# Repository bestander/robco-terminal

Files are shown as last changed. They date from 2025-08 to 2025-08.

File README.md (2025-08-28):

# Fallout RobCo Terminal Project

A fully functional Fallout-style terminal interface for ESP32-S3 with 7" display, featuring authentic RobCo Industries theming, MQTT integration with Home Assistant, and text editor capabilities.

Demo

## Hardware Requirements

- ESP32-S3 HMI 8M PSRAM 16M Flash with 7" 800x480 RGB LCD display
- USB keyboard (USB host implemented by Raspberry Pi Pico connected via UART; firmware: https://github.com/bestander/pi-pico-usb-uart-host)
- WiFi network with Home Assistant + MQTT broker

## Hardware Reference

- [7" 800*480 with ESP32-S3](https://www.aliexpress.us/item/3256807606021455.html)
- USB keyboard [40% mechanical fits the STL](https://www.aliexpress.us/item/3256808357667662.html)
- [Raspberry Pi Pico](https://www.amazon.com/Raspberry-Pi-Pico/dp/B09KVB8LVR) to be used as extension board and a USB HID master
- [Micro USB OTG cable](https://www.amazon.com/dp/B0BX9FSCFH) to connect the keyboard to Pico
- USB-A - USB-C cable to connect the keyboard to the OTG cable
- [Right angle USBC cable](https://www.amazon.com/dp/B0DQS6FTX3) to power and flash the ESP32-S3 board when mounted
- [Frensel lense](https://www.amazon.com/dp/B015NR7XGS) for CRT display affect
- 2 LED and 100-150 Ohm resistors and wire soldered to pins 17 and 21 on Pi Pico for additional signaling

## 3D Print case

See [assets/stl](./assets/stl) for all the 3D printed parts. You'll need a few screws to connect the pieces and a drop of glue to secure wall rest to the keyboard part to prevent it from shaking. 
Feel free to fork the design in [onshape](https://cad.onshape.com/documents/a596f804bfbdc16828dea787/w/d24c8487b87e16e2d8c3f80b/e/312ff6ea062bc67b4dcde5d5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).

## Features

✅ **Authentic Fallout Terminal Experience**
- RobCo Industries boot sequence
- Green terminal text on black background
- Blinking cursor animation
- Terminal-style UI navigation

✅ **Home Assistant Integration**
- MQTT command/control interface
- Real-time status updates
- Conditional menu items based on device states

✅ **Navigation System**
- Multi-level menu navigation
- USB keyboard support (Arrow keys, Enter, Escape)
- Context-sensitive menu items

✅ **Text Editor** (not implemented)
- Built-in log editor
- File-based storage
- Terminal-style editing interface

## Configuration

```yaml
wifi_password: "your_wifi_password"
api_encryption_key: "32-character-key-generated-by-esphome"
ota_password: "your_ota_password"
mqtt_broker: "192.168.1.100"  # Your Home Assistant IP
mqtt_username: "your_mqtt_username"
mqtt_password: "your_mqtt_password"
```

## Home Assistant: MQTT Configuration

1. **Install the Mosquitto broker add-on** (recommended):
   - Go to **Settings > Add-ons > Add-on Store**.
   - Search for "Mosquitto broker" and install it.
   - Start the add-on.

2. **Enable the MQTT integration:**
   - Go to **Settings > Devices & Services**.
   - Click **Add Integration** and search for "MQTT".
   - Enter your broker details (host, port, username, password) matching your ESPHome YAML configuration.
   - Save and finish setup.

3. **Verify connection:**
   - Go to **Settings > Devices & Services > MQTT**.
   - Click **Configure** and use "Listen to a topic" (enter `#` to see all messages) to verify ESPHome is publishing.

4. **Troubleshooting:**
   - Check the Mosquitto broker logs in **Settings > Add-ons > Mosquitto broker > Log**.
   - Ensure your ESPHome device and Home Assistant are on the same network and credentials match.

For more details, see the [Home Assistant MQTT docs](https://www.home-assistant.io/integrations/mqtt/).

## Home Assistant: Example MQTT Scripts & Automations

### Required MQTT Entities

1. **Script: Publish Door State**

Add this to your `scripts.yaml`:
```yaml
publish_garage_state:
  alias: Publish Garage Door State
  sequence:
    - service: mqtt.publish
      data:
        topic: garage/state
        payload: "{{ state }}"
```

Call this script with `state: opened` or `state: closed` when your automation opens/closes the door.

2. **Script: Listen for Open Command with Password**

Add this to your `automations.yaml`:
```yaml
- alias: Open Garage Door via MQTT Password
  trigger:
    - platform: mqtt
      topic: garage/door/open
  condition:
    - condition: template
      value_template: "{{ trigger.payload == 'YOUR_PASSWORD' }}"
  action:
    - service: script.publish_garage_state
      data:
        state: opened
    # Add your open door action here
```

3. **Script: Listen for Close Command**

Add this to your `automations.yaml`:
```yaml
- alias: Close Garage Door via MQTT
  trigger:
    - platform: mqtt
      topic: garage/door/close
  action:
    - service: script.publish_garage_state
      data:
        state: closed
    # Add your close door action here
```

**Note:**
- Replace `YOUR_PASSWORD` with your actual password.
- Add your actual door open/close service calls in the `action` sections.
- Make sure the `script.publish_garage_state` script is available in Home Assistant.

For more details, see the [Home Assistant MQTT docs](https://www.home-assistant.io/integrations/mqtt/).

## Troubleshooting

### Display Issues
- Check SPI pin connections
- Verify display dimensions in configuration
- Ensure adequate power supply

### Keyboard Not Working
- Verify USB host is enabled
- Check USB cable and connections
- Monitor logs for keyboard detection

### MQTT Connection Issues
- Verify Home Assistant MQTT broker settings
- Check network connectivity
- Validate MQTT credentials

### Debug Logging

Enable verbose logging:

```yaml
logger:
  level: VERBOSE
  logs:
    robco_terminal: VERBOSE
```

## ESPHome Compile and Run

To compile the firmware:

```
source .venv/bin/activate && esphome compile robco_terminal.yaml
```

To upload and run the firmware (OTA or USB):

```
source .venv/bin/activate && esphome run robco_terminal.yaml
```

To upload via OTA (WiFi):

```
source .venv/bin/activate && esphome upload robco_terminal.yaml --device robco-terminal.local
```

To view device logs:

```
source .venv/bin/activate && esphome logs robco_terminal.yaml
```

## Contributing

Feel free to submit issues and enhancement requests!

## License

This project is for educational and personal use. Fallout and RobCo Industries are trademarks of Bethesda Softworks.

The 3d design is derived from a very talented and inspiring [work by Lewin Day](https://hackaday.com/2024/05/21/home-automation-terminal-has-great-post-apocalyptic-look/).

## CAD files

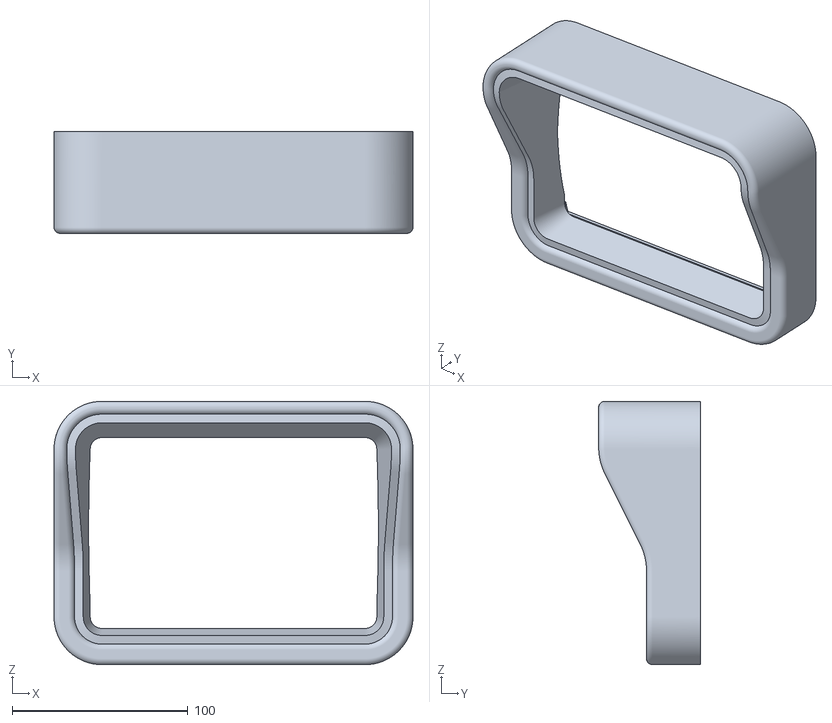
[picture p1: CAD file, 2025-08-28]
assets/stl/Bezel - bezel.stl
204.0 x 57.8 x 149.6

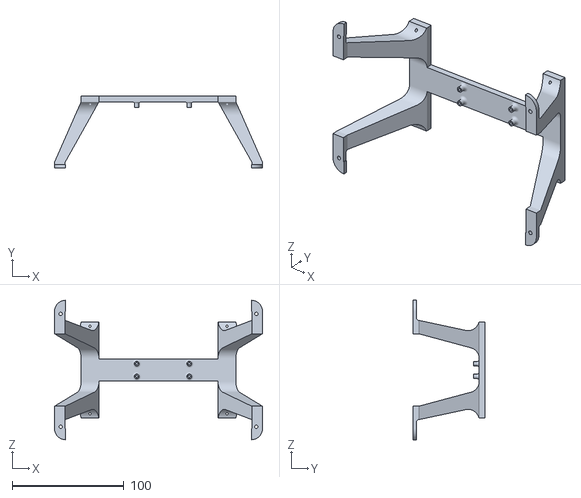
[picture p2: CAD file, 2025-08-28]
assets/stl/Bezel - bracket.stl
186.0 x 64.0 x 124.8

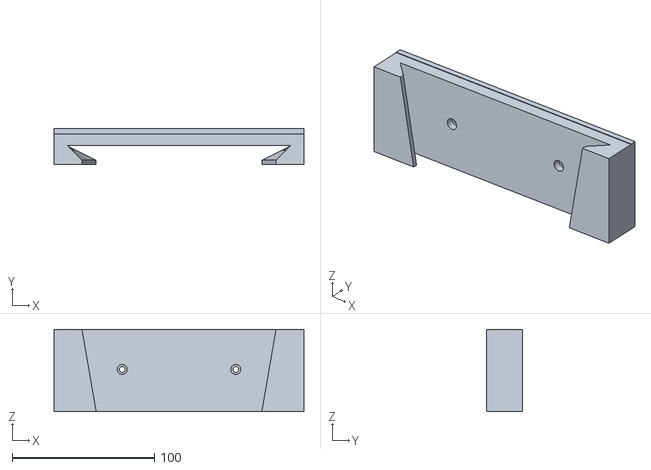
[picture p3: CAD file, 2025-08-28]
assets/stl/Holder - wall plate.stl
176.0 x 25.0 x 58.0

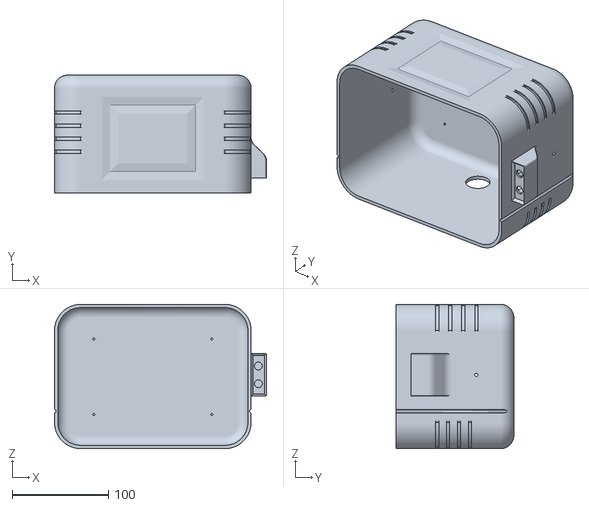
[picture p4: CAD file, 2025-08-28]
assets/stl/Case.stl
219.9 x 122.1 x 149.6

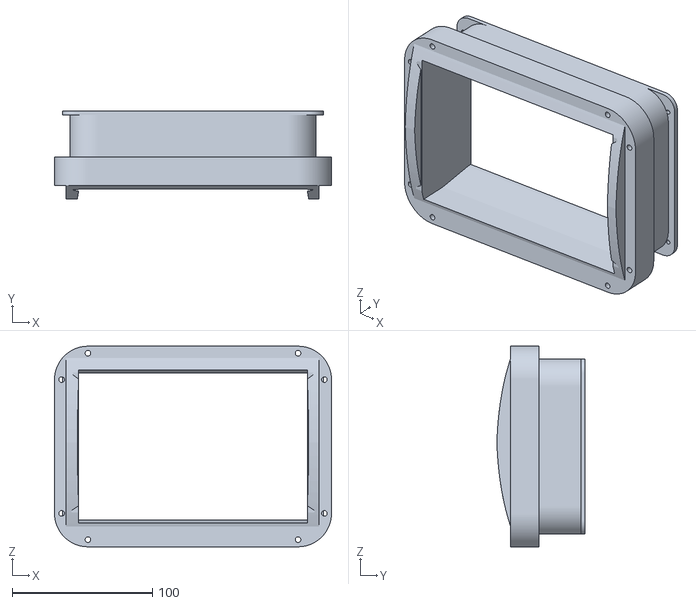
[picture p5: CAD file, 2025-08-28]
assets/stl/Bezel - inset.stl
197.2 x 62.8 x 142.8

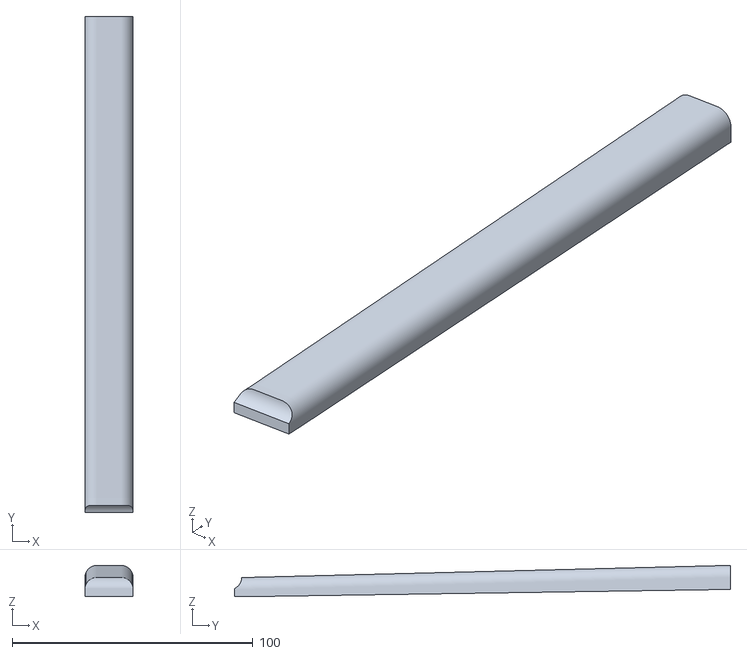
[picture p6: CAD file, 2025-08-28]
assets/stl/Holder - wall rest.stl
20.0 x 206.1 x 13.0

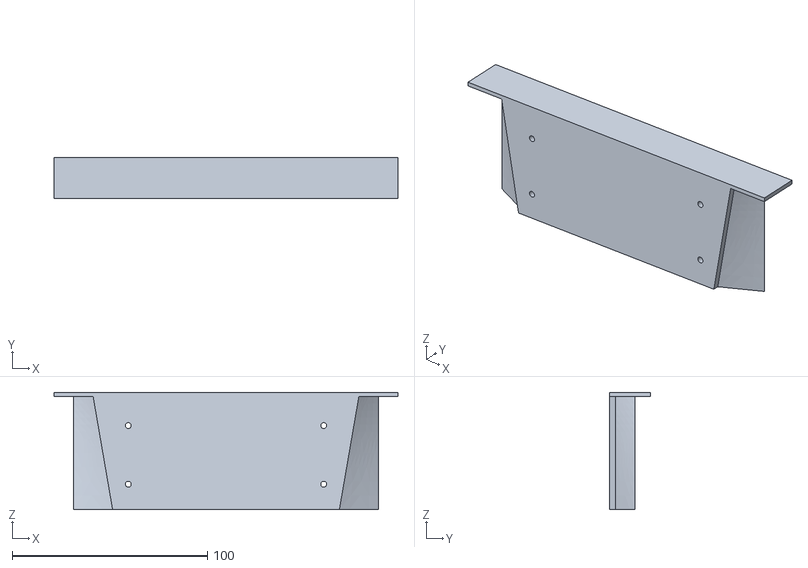
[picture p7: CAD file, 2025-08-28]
assets/stl/Holder - connector.stl
176.0 x 21.0 x 60.0

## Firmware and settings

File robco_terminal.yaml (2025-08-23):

esphome:
  name: robco-terminal
  friendly_name: RobCo Terminal
  platformio_options:
    board_build.flash_mode: dio
    board_build.psram_type: opi
    board_build.flash_size: 16MB
    build_flags:
      - -DCORE_DEBUG_LEVEL=1
      - -DCONFIG_ASYNC_TCP_STACK_SIZE=8192
      - -DCONFIG_ASYNC_TCP_PRIORITY=10

esp32:
  board: esp32-s3-devkitc-1
  flash_size: 16MB
  partitions: default_16MB.csv
  framework:
    type: esp-idf
    version: 5.3.0
    components:
      - name: espressif/esp_lvgl_port
        ref: 2.3.2
      - name: espressif/esp_lcd_touch_gt911
        ref: 1.1.0
      - name: lvgl/lvgl
        ref: 9.2.2
  variant: esp32s3

logger:
  level: INFO
  baud_rate: 115200
  hardware_uart: UART0
  logs:
    component: INFO
    robco_display: INFO
    ota: INFO
    wifi: INFO

psram:
  mode: octal
  speed: 80MHz

wifi:
  ssid: !secret wifi_ssid
  password: !secret wifi_password
  power_save_mode: none
  fast_connect: true
  output_power: 20dB
  reboot_timeout: 0s

mqtt:
  broker: !secret mqtt_broker
  port: 1883
  username: !secret mqtt_username
  password: !secret mqtt_password

captive_portal:

ota:
  platform: esphome
  password: !secret ota_password
  port: 3232

safe_mode:
  reboot_timeout: 10min
  num_attempts: 3

external_components:
  - source:
      type: local
      path: components

pico_io_extension:
  id: pico_io
  rx_pin: 17
  tx_pin: 18

robco_display:
  id: test
  pico_io_extension: pico_io
  red_light_pin: 21
  green_light_pin: 17

text_sensor:
  - platform: mqtt_subscribe
    name: "Vault Door State"
    id: vault_door_state
    topic: garage/state
    on_value:
      then:
        - lambda: |-
            id(test).set_vault_door_state(x);

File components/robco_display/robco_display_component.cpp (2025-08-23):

#include "robco_display_component.h"
#include "crt_terminal_renderer.h"
#include "esphome/core/log.h"
#include "esp_timer.h"
#include "esphome/components/mqtt/mqtt_client.h"

namespace esphome
{
    namespace robco_display
    {

        static const char *TAG = "RobcoDisplayComponent";

        void RobcoDisplayComponent::set_pico_io_extension(esphome::pico_io_extension::PicoIOExtension *ext)
        {
            pico_io_ext_ = ext;
            if (pico_io_ext_)
            {
                pico_io_ext_->set_key_press_callback([this](uint8_t keycode, uint8_t modifiers)
                                                     { this->on_key_press(keycode, modifiers); });
            }
        }

        // Helper to get current time in milliseconds (replace with ESP-IDF API if needed)
        uint32_t RobcoDisplayComponent::get_millis()
        {
            return esp_timer_get_time() / 1000;
        }

        void RobcoDisplayComponent::on_key_press(uint8_t keycode, uint8_t modifiers)
        {
            ESP_LOGI(TAG, "RobcoDisplay received key press: code=0x%02X, modifiers=0x%02X", keycode, modifiers);
            // Save previous menu stack and selected index
            int prev_selected = menu_state_.get_selected_index();
            std::vector<MenuEntry> *current_menu = &menu_;
            const auto &menu_stack = menu_state_.get_menu_stack();
            for (size_t i = 0; i < menu_stack.size(); ++i)
            {
                int idx = menu_stack[i];
                if (idx >= 0 && idx < current_menu->size())
                {
                    current_menu = &(*current_menu)[idx].subitems;
                }
            }
            // Password entry mode
            if (menu_state_.is_password_entry_mode())
            {
                if (keycode == 0x2A)
                { // Backspace
                    menu_state_.remove_password_char();
                }
                else if (keycode == 0x28)
                { // Enter
                    std::string password = menu_state_.get_password();
                    // Send MQTT with password as payload
                    ESP_LOGI(TAG, "Sending MQTT open with password: %s", password.c_str());
                    esphome::mqtt::global_mqtt_client->publish("garage/door/open", password, 0, false);
                    blink_active_ = green_light_pin_;
                    blink_start_ms_ = get_millis();
                    last_blink_ms_ = get_millis();
                    led_state_ = false;
                    set_pin(blink_active_, 0);
                    menu_state_.end_password_entry();
                }
                else if (keycode >= 0x04 && keycode <= 0x1D)
                { // a-z
                    char c = 'a' + (keycode - 0x04);
                    menu_state_.append_password_char(c);
                }
                else if (keycode >= 0x1E && keycode <= 0x27)
                { // 1-9,0
                    char c = (keycode == 0x27) ? '0' : '1' + (keycode - 0x1E);
                    menu_state_.append_password_char(c);
                }
                render_menu();
                return;
            }
            // Check if action is triggered
            if (keycode == 0x28 && prev_selected >= 0 && prev_selected < current_menu->size())
            {
                const auto &entry = (*current_menu)[prev_selected];
                if (entry.title == "Open Vault Door")
                {
                    menu_state_.start_password_entry("Enter password to open vault door:");
                }
                else if (entry.title == "Close Vault Door")
                {
                    ESP_LOGI(TAG, "Closing vault door");
                    esphome::mqtt::global_mqtt_client->publish("garage/door/close", std::string(""), 0, false);
                    blink_active_ = red_light_pin_;
                    blink_start_ms_ = get_millis();
                    last_blink_ms_ = get_millis();
                    led_state_ = false;
                    set_pin(blink_active_, 0);
                }
            }
            menu_state_.on_key_press(keycode);
            render_menu();
        }

        void RobcoDisplayComponent::set_pin(uint8_t pin, bool state)
        {
            if (pico_io_ext_)
                pico_io_ext_->setPin(pin, state);
        }
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

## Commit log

2025-07-26 updated board definition and removed platform.io
2025-07-27 wip: arduino lib
2025-08-03 Add WiFi support and OTA safety system
    - Enable WiFi connectivity for remote management
    - Add OTA Safety component to prevent display interference during updates
    - Create comprehensive OTA update script with safety checks
    - Fix WiFi interference with display rendering by removing interrupt blocking
    - Add web server endpoints for OTA management
    - Optimize display timing for WiFi coexistence
    - Add tasks.json for ESPHome development workflow
    Resolves jittery screen updates when WiFi is enabled.
    [robco_terminal.yaml]
2025-08-03 added pin based keyboard
2025-08-14 keyboard controller via pi pico over uart
2025-08-15 testing other direction communication with pico: setting pins 17 and 21 on key press a and s
2025-08-15 compiles and starts, no screen yet
    [default_16MB.csv]
2025-08-17 added pi pico integration
2025-08-18 added fixedsys monospace font
    [crt_terminal_renderer.cpp, robco_terminal.yaml]
2025-08-28 added BOM and STL files
    [Bezel - bezel.stl, Bezel - bracket.stl, Bezel - inset.stl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]
